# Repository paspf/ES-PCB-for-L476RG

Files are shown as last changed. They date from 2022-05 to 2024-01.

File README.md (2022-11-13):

# ES-PCB for Nucleo L476RG
The boad was developed for teaching purposes in the embedded systems laboratory. It is connected to the ST-MORPHO connectors on the Nucleo L476RG. It adds 8 LEDs, two buttons, four WS2812b LEDs and a display to the Nucleo. This git contains all KiCad files of the project. In the release section you can find the corresponding gerber files. 

An application demo can be found at [ES-PCB-for-L476RG-demo](https://github.com/paspf/ES-PCB-for-L476RG-demo).

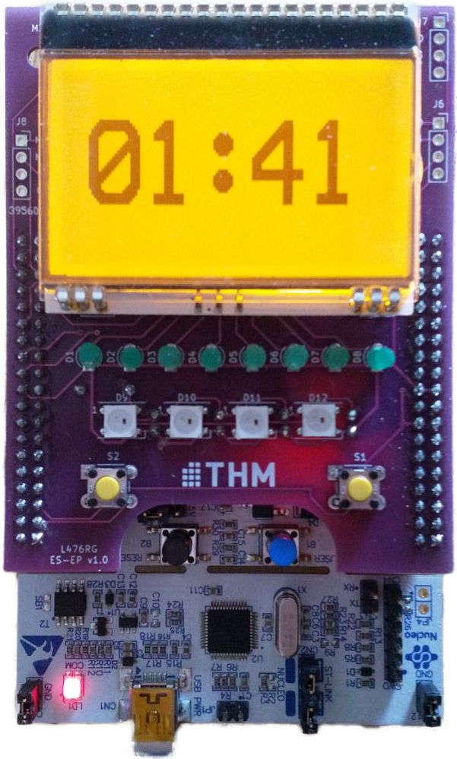
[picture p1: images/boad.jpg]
Image of the PCB


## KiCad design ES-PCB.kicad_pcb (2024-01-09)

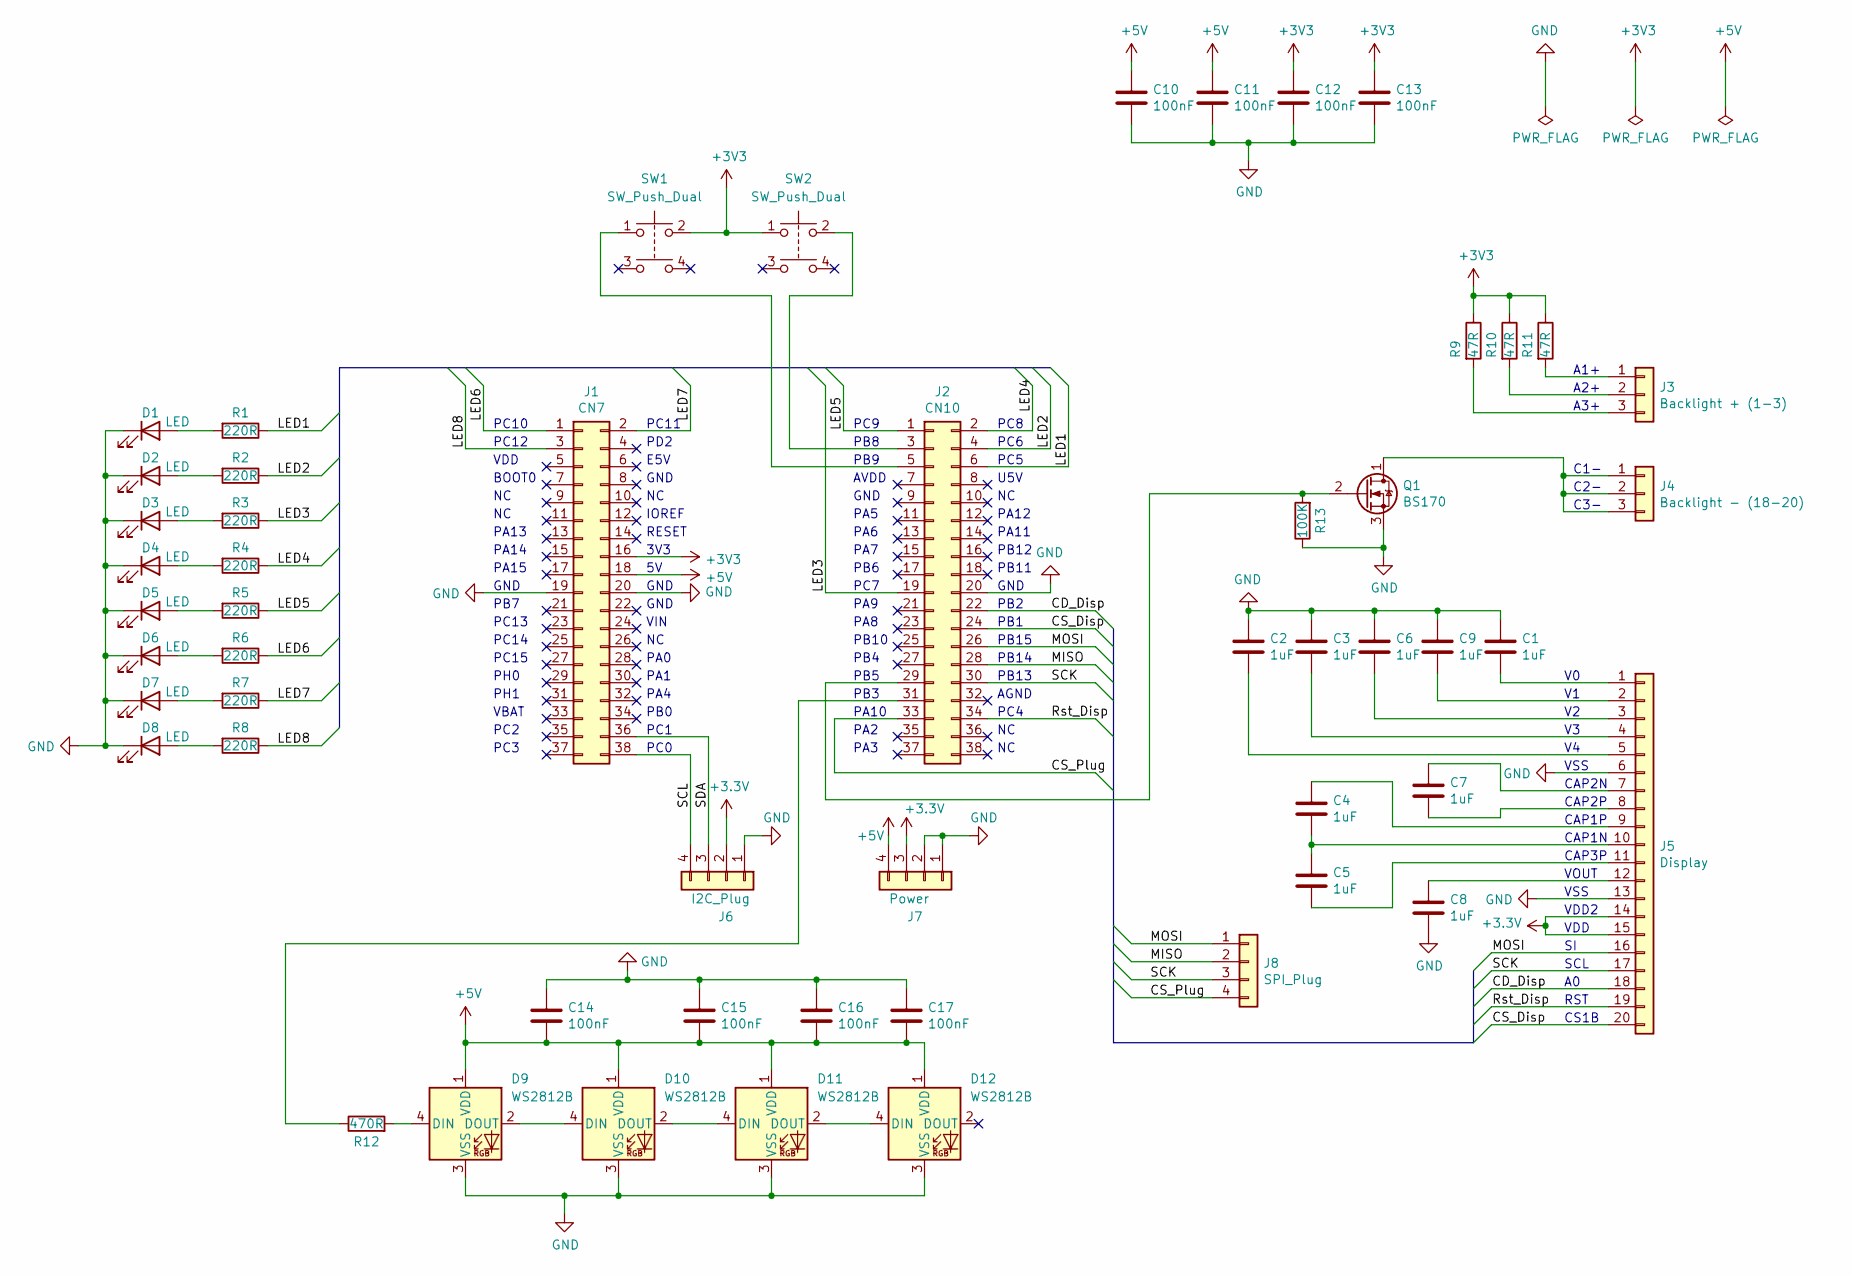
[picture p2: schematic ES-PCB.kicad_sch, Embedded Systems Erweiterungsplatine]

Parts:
C1, C2, C3, C4, C5, C6, C7, C8, C9: 1uF; C_Rect_L7.0mm_W2.0mm_P5.00mm
C10, C11, C12, C13, C14, C15, C16, C17: 100nF; C_Disc_D3.0mm_W2.0mm_P2.50mm
D1, D2, D3, D4, D5, D6, D7, D8: LED; LED_D3.0mm_Clear
D9, D10, D11, D12: WS2812B; LED_WS2812B_PLCC4_5.0x5.0mm_P3.2mm
J1: CN7; PinSocket_2x19_P2.54mm_Vertical
J2: CN10; PinSocket_2x19_P2.54mm_Vertical
J3: Backlight + (1-3); PinSocket_1x03_P2.54mm_Vertical
J4: Backlight - (18-20); PinSocket_1x03_P2.54mm_Vertical
J5: Display; PinSocket_1x20_P2.54mm_Vertical
J6: I2C_Plug; PinSocket_1x04_P2.54mm_Vertical
J7: Power; PinSocket_1x04_P2.54mm_Vertical
J8: SPI_Plug; PinSocket_1x04_P2.54mm_Vertical
Q1: BS170; TO-92_Inline
R1, R2, R3, R4, R5, R6, R7, R8: 220R; R_Axial_DIN0207_L6.3mm_D2.5mm_P10.16mm_Horizontal
R9, R10, R11: 47R; R_Axial_DIN0207_L6.3mm_D2.5mm_P10.16mm_Horizontal
R12: 470R; R_Axial_DIN0207_L6.3mm_D2.5mm_P10.16mm_Horizontal
R13: 100K; R_Axial_DIN0207_L6.3mm_D2.5mm_P10.16mm_Horizontal
SW1, SW2: SW_Push_Dual; SW_PUSH_6mm_H5mm

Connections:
+5V: C10.1, C11.1, C14.2, C15.2, C16.2, C17.2, D9.1 (VDD), D10.1 (VDD), D11.1 (VDD), D12.1 (VDD), J1.18, J7.4
/CD_Disp: J2.22, J5.18
/CS_Disp: J2.24, J5.20
/CS_Plug: J2.33, J8.4
/LED1: J2.6, R1.1
/LED2: J2.4, R2.1
/LED3: J2.19, R3.1
/LED4: J2.2, R4.1
/LED5: J2.1, R5.1
/LED6: J1.1, R6.1
/LED7: J1.2, R7.1
/LED8: J1.3, R8.1
/MISO: J2.28, J8.2
/MOSI: J2.26, J5.16, J8.1
/Rst_Disp: J2.34, J5.19
/SCK: J2.30, J5.17, J8.3
/SCL: J1.38, J6.4
/SDA: J1.36, J6.3
GND: C1.1, C2.1, C3.1, C6.1, C8.2, C9.1, C10.2, C11.2, C12.2, C13.2, C14.1, C15.1, C16.1, C17.1, D1.1 (K), D2.1 (K), D3.1 (K), D4.1 (K), D5.1 (K), D6.1 (K), D7.1 (K), D8.1 (K), D9.3 (VSS), D10.3 (VSS), D11.3 (VSS), D12.3 (VSS), J1.19, J1.20, J2.20, J5.6, J5.13, J6.1, J7.1, J7.2, Q1.3 (S), R13.1
unnamed: C1.2, J5.1
unnamed: C2.2, J5.5
unnamed: C3.2, J5.4
unnamed: C4.1, J5.9
unnamed: C4.2, C5.1, J5.10
unnamed: C5.2, J5.11
unnamed: C6.2, J5.3
unnamed: C7.1, J5.7
unnamed: C7.2, J5.8
unnamed: C8.1, J5.12
unnamed: C9.2, J5.2
unnamed: D1.2 (A), R1.2
unnamed: D2.2 (A), R2.2
unnamed: D3.2 (A), R3.2
unnamed: D4.2 (A), R4.2
unnamed: D5.2 (A), R5.2
unnamed: D6.2 (A), R6.2
unnamed: D7.2 (A), R7.2
unnamed: D8.2 (A), R8.2
unnamed: D9.4 (DIN), R12.2
unnamed: D10.2 (DOUT), D11.4 (DIN)
unnamed: D9.2 (DOUT), D10.4 (DIN)
unnamed: D11.2 (DOUT), D12.4 (DIN)
unnamed: J2.3, SW2.2
unnamed: J2.5, SW1.1
unnamed: J2.29, Q1.2 (G), R13.2
unnamed: J2.31, R12.1
unnamed: J3.1, R11.2
unnamed: J3.2, R10.2
unnamed: J3.3, R9.2
unnamed: J4.1, J4.2, J4.3, Q1.1 (D)

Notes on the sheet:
PC5
PH0
GND
PC6
BOOT0
PA13
VDD2
AVDD
PC9
PC7
PA10
IOREF
PA0
PB6
PC11
VDD
RESET
PA11
PA9
CS1B
3V3
PC15
PA4
RST
PB15
PB14
PC12
PB3
CAP1P
C2-
PC1
PB13
CAP2P
PB1
PB8
PA12
PA14
CAP2N
C3-
VSS

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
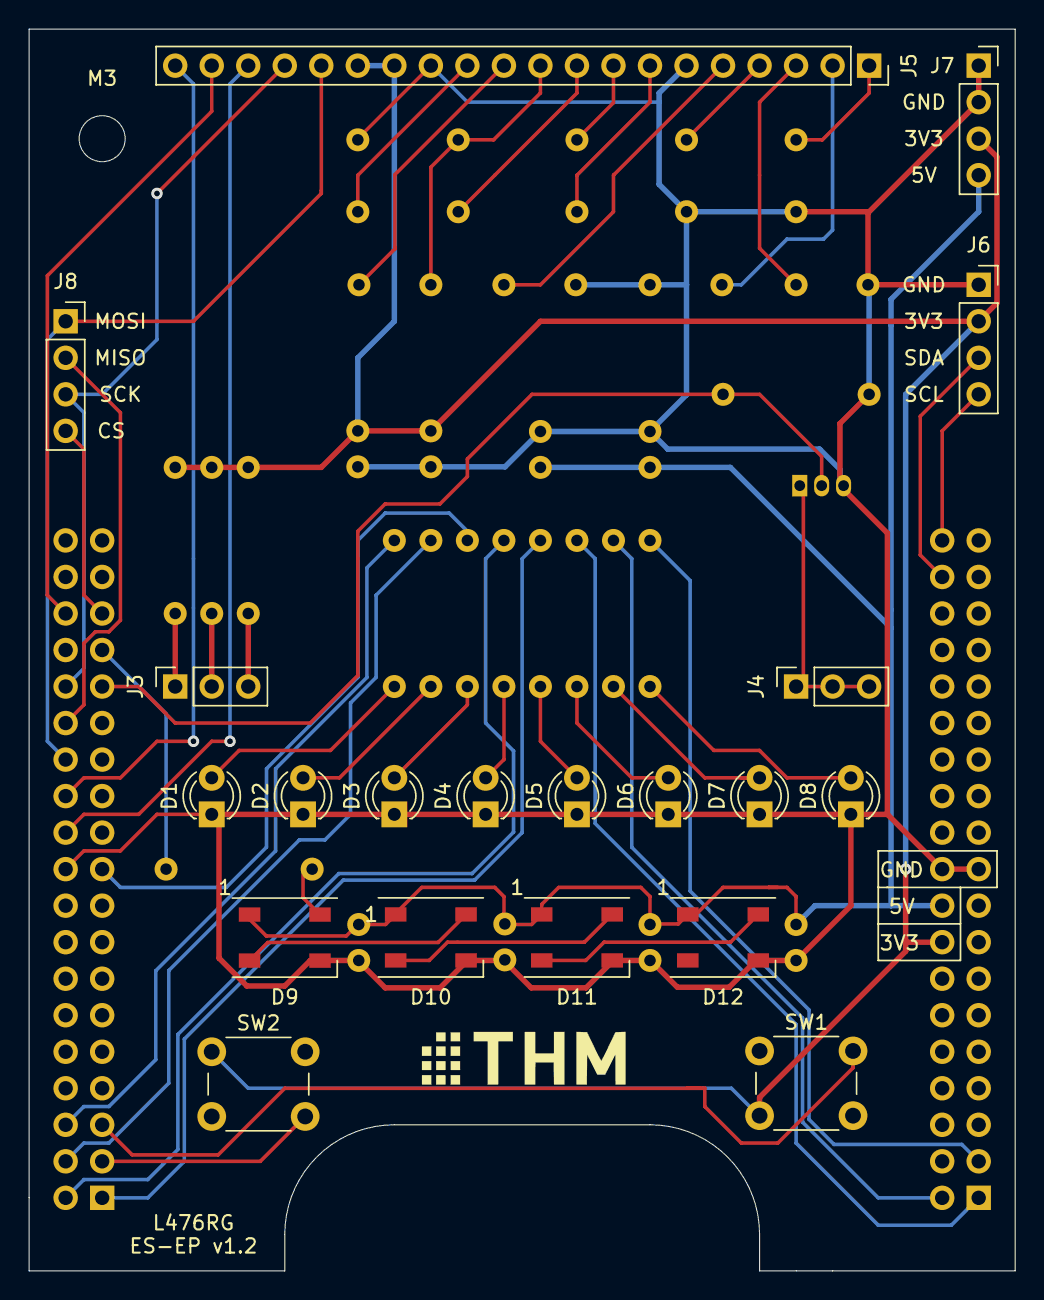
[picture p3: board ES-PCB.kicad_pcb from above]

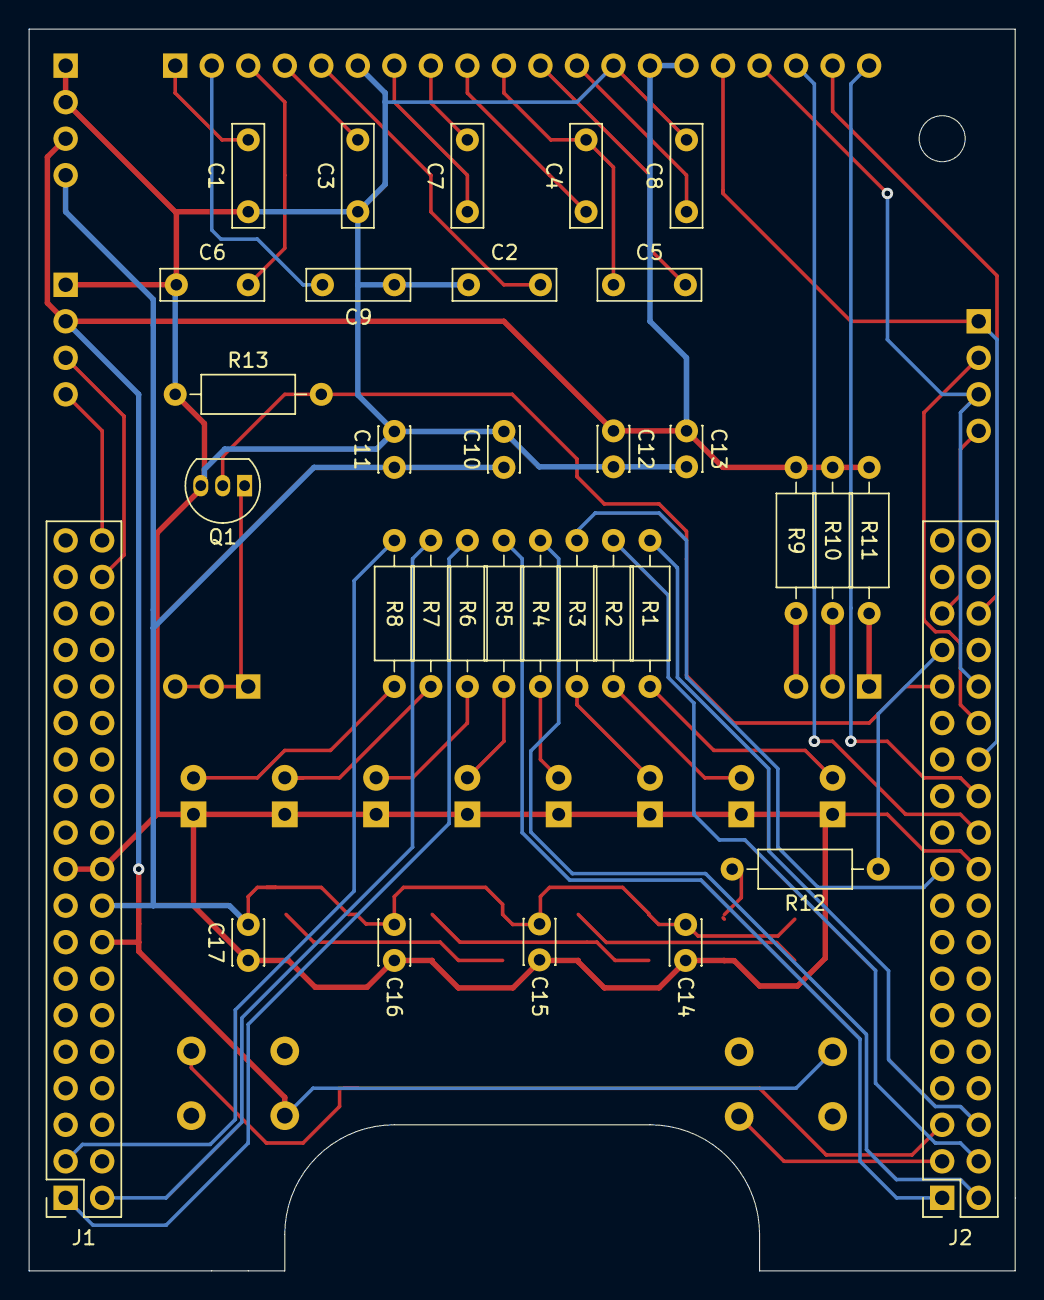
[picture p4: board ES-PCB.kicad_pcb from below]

Board: 2 copper layers, 68.6 x 86.4 mm, 54 parts (33 on the bottom side), 51 nets.

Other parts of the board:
M3: MountingHole_3.2mm_M3

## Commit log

2022-05-07 add kiCad project
    [ES-PCB.kicad_pcb, ES-PCB.kicad_sch, ES-PCB.sch]
2024-01-09 Add silkscreen markers for power pins, update to KiCad 7.
    [ES-PCB.kicad_pcb, ES-PCB.kicad_sch]
